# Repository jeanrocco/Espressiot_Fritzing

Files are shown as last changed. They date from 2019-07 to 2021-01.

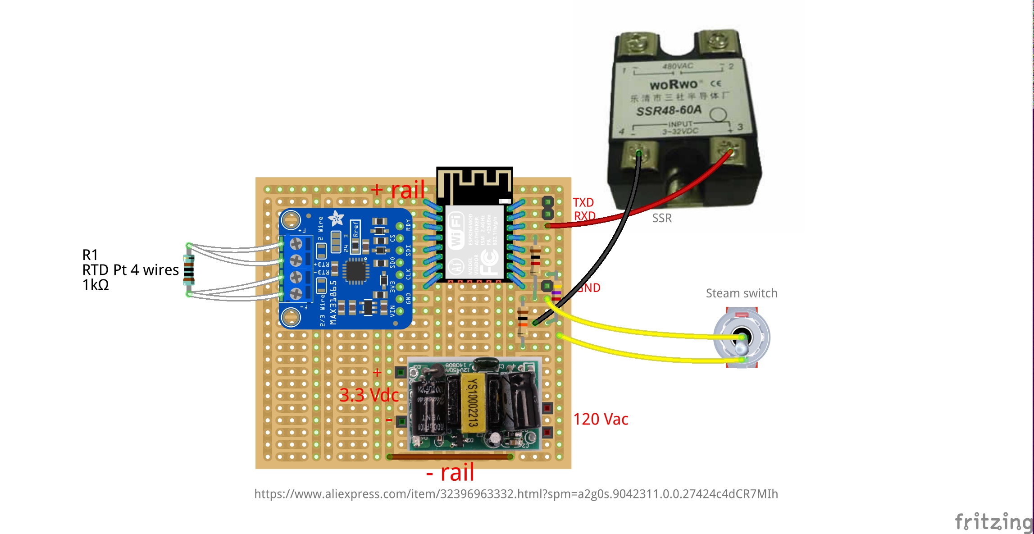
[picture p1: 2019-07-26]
Espressiot_final_bb.jpg

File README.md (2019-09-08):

# Espressiot_Fritzing

My implementation of Espressiot ( https://github.com/Schm1tz1/ESPressIoT ) ...

A good place to file my doc.

Added code for espressiot using a modified Adafruit MAX31865 RTD library and code for a second portable ESP8266 with Oled display.

I made the library non-blocking by changing the 10 msec. (bias enable) and a 65 msec. (conversion time) delays using millis().

I was having issues running the Oled display on the same Espressiot's ESP8266, too much delays I suppose. Lazily, after briefly looking for a non-blocking Oled driver, I decided to use a spare ESP8266 module whose sole purpose would be to get the temperature from an MQTT broker and display it on the Oled. This worked very well, and proved to be very flexible because it is portable.

Every second, the Espressiot-PID code "publishes" the RTD temperature to an MQTT broker, Mosquitto, which is running on a Raspberry PI (it was already running for Home Assistant...). Every 1/2 seconds, the Oled-display-ESP8266's code, which "subscribes" to the MQTT broker temperature, will update the Oled displays.

The file espressiotJR3b7c (https://github.com/jeanrocco/Espressiot_Fritzing/tree/master/espressiotJR3b7c) corrects the closed issue ESPressiot "Tuning loop not doing correct peak to peak temperature"  ( https://github.com/Schm1tz1/ESPressIoT/issues/2 ). This will allow a more accurate autotuning of the P, I and D parameters.

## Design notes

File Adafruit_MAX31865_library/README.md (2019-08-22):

# MODIFIED Adafruit_MAX31865
Arduino Library for Adafruit MAX31865 RTD Sensor

To make the library non-blocking, the "Adafruit_MAX31865::readRTD (void)" function will not be called because of the 10 and 65 msec. delays. It will be done externally using millis() function. In order to do that, "uint8_t  readRegister8(uint8_t addr);", "uint16_t readRegister16(uint8_t addr);" and "writeRegister8(uint8_t addr, uint8_t reg);" are made "public" in Adafruit_MAX31865.h .

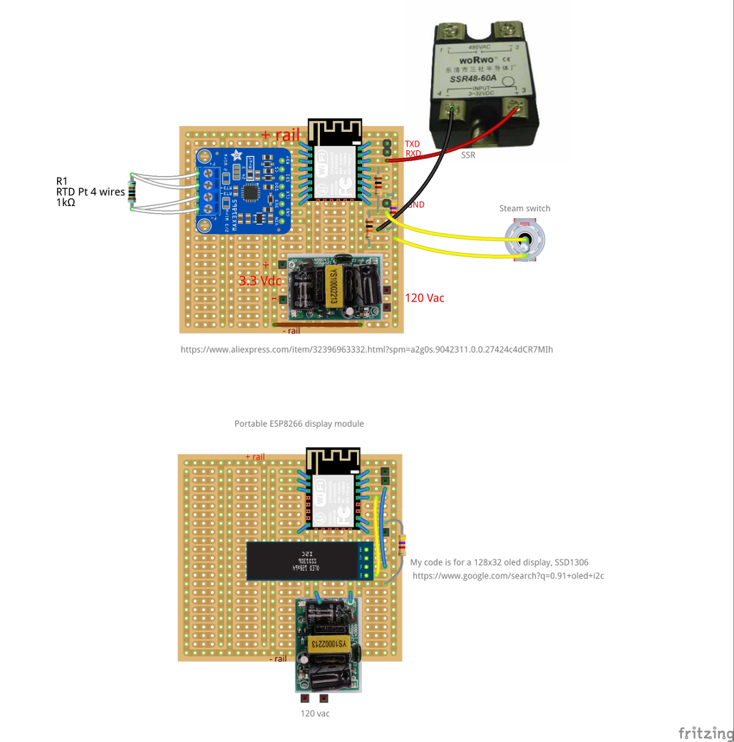
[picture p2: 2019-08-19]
Espressiot_final_Oled_bb_scaledd.png

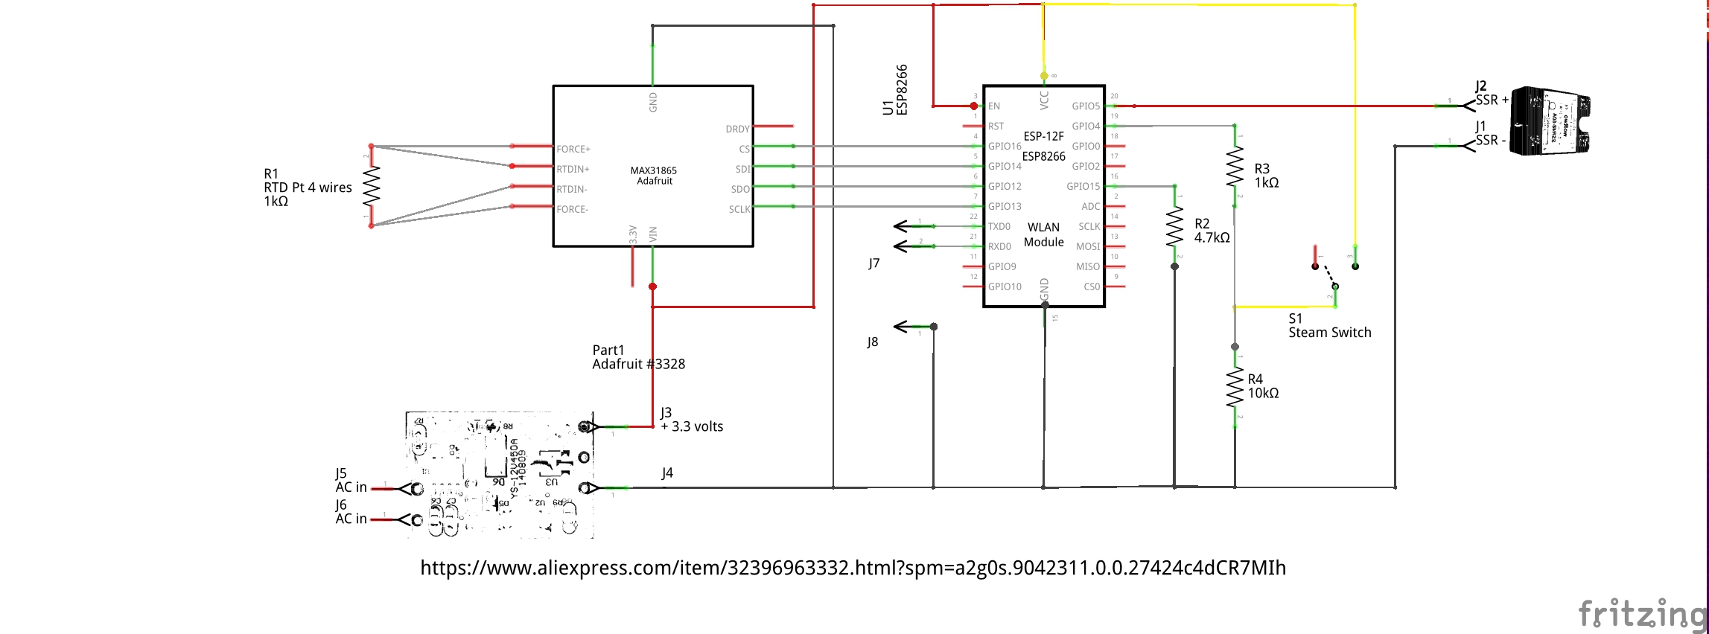
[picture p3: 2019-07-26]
Espressiot_final_schem.jpg

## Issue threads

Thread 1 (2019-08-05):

Autonomous portable temperature display - Code available?

VastSky, 2019-08-05:
Hello jeanrocco,

Your display solution sounds great!

Are you running a MQTT broker to that the autonomous portable temperature display subscribes to, or does the ESP8266 subscribe directly to the MQTT stream?

FYI - I found a great free MQTT tool:   http://mqtt-explorer.com/

Wondering if you might publish your ESP8266 code used for the display so I might attempt to make it work for myself.

Thanks,

Ed

jeanrocco, 2019-08-05:
Hello Ed,

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
I already had (have) an MQTT broker; “ Mosquitto”, running for "Home Assistant" on a dedicated Raspberry Pi. The ESP8266 running Espressiot publishes to topic "ESPressIoT/temp” and the other ESP8266 subscribes to it.
>
> FYI - I found a great free MQTT tool: http://mqtt-explorer.com/ <http://mqtt-explorer.com/>
>
I’m running MQTT.fx.app on a Mac now and then, your’s looks interesting though. I normally use the command line mosquitto_pub and  mosquitto_sub .
> Wondering if you might publish your ESP8266 code used for the display so I might attempt to make it work for myself.
>
>
I will do that as soon as I get back home, after Aug. the 14th, unfortunately I cannot "wake on lan" the machine where the code is right now. I will post how I modified Espressiot to slow down the publish to 1 sec. too. I’m using the standard https://github.com/olikraus/u8g2 <https://github.com/olikraus/u8g2> library.
So  till then !

Cheer !
jrb.
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

jeanrocco, 2019-08-07:
Hello ED,

Ok I uploaded my code to github, it is very crude but it works. I will try to clean it when I get home.

jrb.

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

jeanrocco, 2019-09-08:
Hello Ed.,  are you receiving this message ???

 I just saw that our friend Schm1tz1 locked the "Non blocking oled driver" repository where we were chatting...

About your MQTT broker question, as I explain in my Espressiot_Fritzing's README, I'm using an already existing broker/server running on a Raspberry pi. This was the easiest way for me since I'm running a Docker Home_Assistant app. (https://www.home-assistant.io/docs/installation/docker/) on that Raspberry pi, which contains the Mosquitto MQTT broker.

I just quickly glanced at some Google'd results and found out at "https://github.com/martin-ger/uMQTTBroker/tree/master/examples/uMQTTBrokerSampleOOFull" an interesting MQTT Arduino ESP8266 server that might work for you. I suppose you could just set up this server on the Oled Display ESP8266, since it is not very busy... and use it's built in MQTT client to subscribe to the local host 127.0.0.1 temperature topic. The other ESP8266 running Espressiot_PID would simply have to connect to this broker(server) as it currently does now for 192.168.1.120, in my case.

If you fell like doing this, let me know, I might be interested by this since it would be simpler to run the 2 ESP8266 without implying a third MQTT broker.

.... now that I think about it, when I'll be finished with my Rancillio project, I might look  more closely at that... that is an interesting solution... we'll keep in touch then.

jrb

VastSky, 2019-09-08:
Hey jeanrocco,

ed.rilkoff@ (google's popular email platform)  I thought we might leave Github for conversation.

I recently began to look ESP to ESP communication without the need for a router. ESP-now may do this.

https://forum.arduino.cc/index.php?topic=551310.0

https://www.reddit.com/r/arduino/comments/azlh6u/just_played_around_with_espnow_a_little_its/

I am going to look at using a ESP8266 as a MQTT broker. but, for now I must take care of home maintenance before poor weather arrives.

I have also been spending too much time trying to get a 6 hour 3D print in PETG to succeed. It is torturing me!

Ed

VastSky, 2021-01-24:
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

Hello jeanrocco,

I finally set up mosquito on my RPi, and built your autonomous portable temperature display. Everything works FANTASTIC!!
The response of the web interface is also much faster when accessing the IP of the EspressIoT - did you fix this?

I also updated to us your tuning with the "MaxUpperT=0, MaxLowerT=0" changes.

Would you have PID settings for the Miss Silvia that you like? I would love to try them.

Would you have any recommendations to use the PID tuning?

Thanks! - Ed

jeanrocco, 2021-01-25:
Hello Ed,

I haven't played with that code for awhile, I got bored by instabilities,
and finally bought a Dual boiler Breville all pid controlled... had a good
price (1000 can$) last year I couldn't resist ... not as solid as the
Rancillio, but makes an excellent coffee.

So the whole arduino pid just now sits in the forgotten pile... on my desk.
I spend my time on " Leaf firewall " development
which gives you a good firewall.

Ok my best wishes for 2021,

jrb.

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

VastSky, 2021-01-25:
Hey jeanrocco,

I agree that PID on a the miss Silvia single boiler will never be successful, but it is still an improvement over the mechanical thermostat. I enjoyed going through your contributions to the EspressIoT.

Glad you are enjoying the Breville. It is nice to have something that just works!

All the best,

Ed

jeanrocco, 2021-01-28:
Hello Ed,

Just not to let you believe I abandoned the ESP’s and Raspberry PIs, I still play with them, but a bit less. For the ESPs (esp8266 and esp32) I was happy to have found epressiot's application since right now, I have not found further interesting projects for them. My fondness for the PIs is still there, but I discarded it as a reliable platform, I now use a APU2E4 ( any APU2.. ) PC engine for my home assistant platform. This Soc is rock solid and never crashes. I run Ubuntu server on it and the Docker version of Home Assistant. I was doing the same last year with a PI but it crashed while I was vacationing down south (Florida :-)… and that’s a No No !!! Those APU2 are a very good inexpensive alternative compared to the Intel NUCs (pricy pricy ) and other Chinese equivalents that don’t necessarily have the encryption AES-NI hardware.

I gave you a hint of my current interest in the LEAF firewall, which runs here on a APU2C2 as my home firewall. If you look at https://bering-uclibc.zetam.org/wiki/Main_Page <https://bering-uclibc.zetam.org/wiki/Main_Page> at the version 5, 6 and 7 of the documentation you will have a glimpse at what I’m talking about. I’m currently, slowly, working on https://bering-uclibc.zetam.org/wiki/Bering-uClibc_7.x_-_User_Guide <https://bering-uclibc.zetam.org/wiki/Bering-uClibc_7.x_-_User_Guide> documentation, and if you read the chapters involving the PIs, you will see that installing a LEAF OS on one makes it a very reliable platform since everything from then on runs in RAM, no failure prone writes to the SD card anymore … You see there are still hopes for the PIs used that way :-). As a matter of fact I couldn’t resist buying myself a "PI Zero W", at 12.95$ Can. even if I have no use for it :-) …  I still can’t believe this 10$ (UStiny board holds a full fledge computer…

Ok so have fun with your projects, and I wish you the very best !

jrb.

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

VastSky, 2021-01-30:
Hey jeanrocco,

Thank you for sharing details on your projects!

It is very frustrating to have your remote monitoring fail when abroad.

The APU2E4 is intriguing hardware, especially with your application of hosting both home automation and LEAF firewall. That looks like a big learning curve. I intend to look at it in greater detail. What sort of home automation tasks have you deployed?

Reliable remote information is a must to give one peace of mind that everything is normal and secure at one's residence when you are away. I am a hobbyist that is easily distracted off course when something interesting presents, rather than maintaining focus on a project underway. I thus play with tech that is low budget like the ESP8266/32, RPi, sOnOff and ASUS wifi routers.

I buy off eBay, AliExpress and Banggood, mostly D1 mini, ESP-01S, NodeMCUv3, ESP32 DevC v4. DS18b20, BME280, BMP280, I2C OLEDs, and sOnOff.
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
VastSky, 2021-02-07:
Hello jeanrocco,

Thank you for the detailed information! I'm working through it. You really have taken HA and network security to the next level!

Do you slope or tow launch/thermal your sailplane? Are you familiar with **[dynamic soaring](https://www.youtube.com/watch?v=4eFD_Wj6dhk&feature=emb_logo)**?  The site I fly is slope, often with thermals. Built a few hotwire cut flying wings.

I discovered a very detailed, well documented **["Espresso-PID"](http://rancilio-pid.de/)** The setup was easy as I only needed to revise the IO, and OLED constructor to match my hardware, and it has DS18b20 as a sensor option.  The project has an active discord channel as well. I have been enjoying this project.

Ed

jeanrocco, 2021-02-08:
Hello Ed,

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
Just being careful :-) … and at the same time these projects keeps me abreast and aware of new technologies …
> Do you slope or tow launch/thermal your sailplane? Are you familiar with dynamic soaring <https://www.youtube.com/watch?v=4eFD_Wj6dhk&feature=emb_logo>? The site I fly is slope, often with thermals. Built a few hotwire cut flying wings.
>
>
I used a bungee for my first sailplane, a gentle lady , then switched to the much more convenient outer-runner motors and lipo batteries. Dynamic soaring requires mountains and a high degree of piloting skill, both of witch I lack :-) !!!

I climb up with the folding props electric motor to about 700 feet, and then hunt for thermals. On active days I can stay up until my transmitter battery weakens, couple of hours with my old NICad one. I used to fly at a club site for  RC control airplanes, and was making everyone jealous for staying in the air that long …

I’m using arf models, like Multiplex Easy glider pro. etc ... . We had a dude in our club that used a hotwire cutter, with steppers to drive it, but I didn’t used that, not enough patience. I don’t fly as much now, my evolving cataracts are slowing me down, and I’m waiting for the operation to clarify all that, well this year hopefully.
> I discovered a very detailed, well documented "Espresso-PID" <http://rancilio-pid.de/> The setup was easy as I only needed to revise the IO, and OLED constructor to match my hardware, and it has DS18b20 as a sensor option. The project has an active discord channel as well. I have been enjoying this project.
>
>
Ok I zipped through that but my german is not very good, and finally found the english docs. The only thing I didn’t like is this blynk cloud gizmo where you have to register for an account … it feels awkward or silly to need a web connection for making a cup of coffee :-) ! There are probably ways to go around that. So since you tried this PID, what are your comments, is it any good, stable and converging to a steady state set-point ???

Ok bye for now, fun exchanging with you as usual… btw where do you live ?

jrb.

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

VastSky, 2021-02-08:
Hello jeanrocco,

I live in Kamloops BC. You can take a look at my **[YT videos](https://www.youtube.com/user/cloudsuck/videos)** . Some of the scratch built stuff. I like planes that are fun and won't make me cry if I crash. Did a few tri and quadcopters too.

Google translate helped make reading through the German pretty simple. I am not using Blynk with it. It is MQTT capable, and wifi telnet serial debug capable which works nicely. Very well documented project. The single boiler of the Rancilio will never maintain a constant delivery temp of brew water, but this PID keeps the "set" temperature very stable without negligible overshoot. The Config.H is where you configure it all with good English comments. This project uses OTA flashing from the Arduino IDE which works well for configuration changes. Those Germans are overachievers!

Sorry to hear that you need to wait for the cataract surgery. I have friends that only wear weak reading glasses after surgery, and colors become vivid after surgery. If you can afford to, pay do it, and get the best surgeon and the best lenses.

Gotta run - at work and we have workers arriving that I must deal with.

Ed

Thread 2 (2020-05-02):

Using PT100RTD sensors and Adafruit MAX31865

ZH-A, 2020-05-02:
Hello! Can I ask some questions, as the author of Espressiot does not answer, but I am eager to understand how all this working))

I also use a similar sensor, only PT100 and with a library pt100rtd.h. But the components are not original, and the 2-wire sensor has a problem with self-heating, the sensor lies a lot when measured about 8 degrees, but after calibration it’s become in norm. Have you encountered such a problem? I would like to try using your code, but I am not good at programming and do not understand how the calibration mechanism can be implemented in your code?

Second question. Did not figure out how to connect to the MQTT server anywhere in the code there is no login and password for, can you tell me how this mechanism should work, please?

And the third problem with the PID. When I change the settings in the web interface is that practically nothing happens; the temperature curve does not change in any way, although the new coefficients are saved and displayed on the screen. Or do they only need to be changed only in code?

VastSky, 2020-05-02:
Sorry, I'm not proficient with code.

I referred to Schm1tz1/ earlier project "cofcon" to adapt the EspressIoT code for use with a DS18B20 temperature sensor. You can find the cofcon project at: https://github.com/Schm1tz1/cofcon

The only reason to use MQTT is to log data from the EspressIoT.  You can set up a MQTT broker on your PC or a Raspberry Pi:
http://www.steves-internet-guide.com/install-mosquitto-broker/
https://www.youtube.com/watch?v=xzHbMlFOu1E

The EspressIoT project is not a broker, but is is a client and will broadcast to a MQTT server. It does work. A nice tool to monitor the MQTT information is found at: http://mqtt-explorer.com/

The EspressIoT web interface does function to change coefficients and settings for me. I have not modified anything other than the temperature sensor type in the original code.

You might find similar projects that go into more explicit detail helpful that do temperature control such as sous vide, or beer brewing.

Good luck - best wishes!

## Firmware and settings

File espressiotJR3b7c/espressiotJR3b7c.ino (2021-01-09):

//
// ESPressIoT Controller for Espresso Machines
// 2016 by Roman Schmitz
//
// Uses PID library
//

#include <PID_v1.h>
#include <ESP8266WiFi.h>

// WIFI

#define WIFI_SSID "WIFI_ID"
#define WIFI_PASS "WIFI_password"

// options for special modules
#define ENABLE_JSON
#define ENABLE_HTTP
#define ENABLE_MQTT

// use simulation or real heater and sensors
//#define SIMULATION_MODE

//
// STANDARD reset values based on Gaggia CC
//
#define S_P 150.0
#define S_I 0.75
#define S_D 500.
#define S_aP 500.0
#define S_aI 0.0
#define S_aD 0.0
#define S_TSET 90.0
#define S_TBAND 5.0

//
// Intervals for I/O
//
#define HEATER_INTERVAL 1000
#define DISPLAY_INTERVAL 1000
#define PID_INTERVAL 200

//
// global variables
//
double gTargetTemp=S_TSET;
double gOvershoot=S_TBAND;
double gInputTemp=20.0;
double gOutputPwr=0.0;
double gP = S_P, gI = S_I, gD = S_D;
double gaP = S_aP, gaI = S_aI, gaD = S_aD;

double tictic=gTargetTemp;

double MaxUpperT=0, MaxLowerT=0;                // declared here to allow cute "serial plotter" output...

unsigned long time_now=0;
unsigned long time_last=0;

boolean tuning = false;
boolean osmode = false;
boolean poweroffMode = false;

int tic = 0;

//
// gloabl classes
//
PID ESPPID(&gInputTemp, &gOutputPwr, &gTargetTemp, gP, gI, gD, P_ON_E, DIRECT);



void setup()
{
  gOutputPwr=0;
  pinMode(4 , INPUT);
  Serial.begin(115200);

  Serial.println("Mounting SPIFFS...");
  if(!prepareFS()) {
    Serial.println("Failed to mount SPIFFS !");
  } else {
    Serial.println("Mounted.");
  }

  /*if (!saveConfig()) {
    Serial.println("Failed to save config");
  } else {
    Serial.println("Config saved");
  }*/

  Serial.println("Loading config...");
  if (!loadConfig()) {
    Serial.println("Failed to load config. Using default values and creating config...");
    if (!saveConfig()) {
     Serial.println("Failed to save config");
    } else {
      Serial.println("Config saved");
    }
  } else {
    Serial.println("Config loaded");
  }
   
  Serial.println("Settin up PID...");

  WiFi.begin(WIFI_SSID, WIFI_PASS);
  Serial.println("");
  Serial.print("MAC address: ");
  Serial.println(WiFi.macAddress());

  while (WiFi.status() != WL_CONNECTED) {
    delay(500);
    Serial.print(".");
  }
  
  Serial.println("");
  Serial.println("WiFi connected.");
  Serial.print("IP address: ");
  Serial.println(WiFi.localIP());

  #ifdef ENABLE_HTTP
  setupWebSrv();
  #endif
  
  #ifdef ENABLE_MQTT
  setupMQTT();
  #endif

  // setup components
  setupHeater();
  setupSensor();

  // start PID
  ESPPID.SetTunings(gP, gI, gD, P_ON_E);
  ESPPID.SetSampleTime(PID_INTERVAL);
  ESPPID.SetOutputLimits(0, 1000);
  ESPPID.SetMode(AUTOMATIC);
 
  time_now=millis();
  time_last=time_now;
    
}

void serialStatus() {
  Serial.print(gInputTemp, 2); Serial.print(" ");
  Serial.print(gTargetTemp, 2); Serial.print(" ");
  Serial.print(tictic, 2); Serial.print(" ");
  Serial.print(MaxLowerT, 2); Serial.print(" ");      // have a look at the " Tools -> Serial Plotter " when running auto-tune
  Serial.print(MaxUpperT, 2); Serial.print(" ");      // this gives a cute display !
//  Serial.print(time_now); Serial.print(" ");
//  Serial.print(gOutputPwr, 2); Serial.print(" ");
//  Serial.print(gP, 2); Serial.print(" ");
//  Serial.print(gI, 2); Serial.print(" ");
//  Serial.print(gD, 2); Serial.print(" ");
//  Serial.print(ESPPID.GetKp(), 2); Serial.print(" ");
//  Serial.print(ESPPID.GetKi(), 2); Serial.print(" ");
//  Serial.print(ESPPID.GetKd(), 2); Serial.print(" ");
//  Serial.print(digitalRead(4));
  Serial.println("");
}

void loop() {
  time_now=millis();

  updateTempSensor(); 
  gInputTemp=getTemp();

  if(abs(time_now-time_last)>=PID_INTERVAL or time_last > time_now) {
    if(poweroffMode==true) {
      gOutputPwr=0;
      setHeatPowerPercentage(0);
    }
    else if(tuning==true)
    {
      tuning_loop();
    }
    else  {
      if( !osmode && abs(gTargetTemp-gInputTemp)>=gOvershoot ) {        
        ESPPID.SetTunings(gaP, gaI, gaD, P_ON_E);
        osmode=true;
      }
      else if( osmode && abs(gTargetTemp-gInputTemp)<gOvershoot ) {
        ESPPID.SetTunings(gP,gI,gD,P_ON_E);
        osmode=false;
      }
      if(ESPPID.Compute()==true) {   
        setHeatPowerPercentage(gOutputPwr);
      }
    }        
    
    #ifdef ENABLE_MQTT
    loopMQTT();
    #endif

    if (tic == 0) tictic = gTargetTemp +1;
    serialStatus();
    tic++;
    tictic = gTargetTemp;
    if (tic == 5) tic = 0;
    
    time_last=time_now;
  }

  updateHeater();
  
  #ifdef ENABLE_HTTP
  loopWebSrv();
  #endif 
  
}

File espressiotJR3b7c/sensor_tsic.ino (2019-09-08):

//
// ESPressIoT Controller for Espresso Machines
// 2016 by Roman Schmitz
//
// TSIC-Sensors using Arduino-TSIC-Library
//

#ifndef SIMULATION_MODE

//#include <TSIC.h>
#include <Adafruit_MAX31865.h>


//Use software SPI: CS, DI, DO, CLK
Adafruit_MAX31865 maxJR = Adafruit_MAX31865(16, 14, 12, 13);
 
//#define TSIC_SIG 4 // D4 pin of NodeMCU just in the right position


#define RREF       4300.0      // resistance de reference
#define RNOMINAL   1000.0      // rtd a 0 C.

int SMP_TIME1 = 10;   // pour le bias enable...
int SMP_TIME2 = 65;   // pour le one shot, qui demarre la conversion
uint16_t cnt1 = 0; uint16_t cnt2 = 0;
int nread = 8;        // nombre de valeurs analogiques pour la moyenne...
boolean biasEnab = false;
boolean oneShot = false;

float readings[8];
uint16_t idx = 0;
float total = 22.0 * nread;
float moy = 22.0;

 
//#define ACCURACY 0.1

//TSIC TSens1(TSIC_SIG);

float lastT = 0.0;
float SumT = 0.0;
float lastErr = 0.0;
int CntT = 0;
uint16_t raw_temp = 0;
unsigned long lastSensTime;
uint8_t sm = 1;                 // demarre avec l'etat 1...
uint16_t rtd = 1000;

void setupSensor() {  
  maxJR.begin(MAX31865_4WIRE);  // set to 2WIRE or 4WIRE as necessary
  for ( int lect = 0; lect < nread; lect++ ) {  // initialize 8 readings to 22.0 degres...
    readings[lect] = 22.0;
  }
  total = 22.0 * nread;
//  lastSensTime=millis();
  sm = 1;                       // etat 1...
}

void updateTempSensor() {
  
  switch (sm) {

    case 1:
      
      maxJR.clearFault();
      maxJR.enableBias(true);
      lastSensTime = millis();
      cnt1 = 0; cnt2 = 0;
      sm = 2;
      break;
      
    case 2:

      cnt1++;
      if (abs(millis() - lastSensTime) >= SMP_TIME1) {
        
        uint8_t registre = maxJR.readRegister8(0);  // lire le registre de configuration adr 0
        registre |= 0x20;                           // le bit pour oneshot
        maxJR.writeRegister8(0, registre);          // et demarre la conversion
        lastSensTime = millis();
        sm = 3;
        
      }
     break;
      
    case 3:

       cnt2++;
       if (abs(millis() - lastSensTime) >= SMP_TIME2) {

        rtd = maxJR.readRegister16(0x01);
        rtd >>= 1;                                  // enleve le bit fault...
        float curT = maxJR.temperature(RNOMINAL, RREF, rtd);
      
/*      // very simple selection of noise hits/invalid values 
        if(abs(curT-lastT)<1.0 || lastT<1) {
        SumT+=curT;
        CntT++;        
        } 
*/
        total = total - readings[idx];    // enleve la derniere valeur...
        readings[idx] = curT;
        total = total + readings[idx];
        idx++;
        if (idx >= nread) {
          idx = 0;
        }

        
        sm = 1; 
        
//        Serial.print("cnt1 = "); Serial.print(cnt1); Serial.print("  cnt2 = "); Serial.println(cnt2);
//        J'ai ~ 70 usec de loop ... cnt1= 144 pour 10 msec et cnt2= 929 pour 65 msec... ca clanche en ta !
       }

       
      break;
  }
  
  
  
/*  if (abs(millis() - lastSensTime) >= TSIC_SMP_TIME) {
    if(TSens1.getTemperature(&raw_temp)) {
      float curT = TSens1.calc_Celsius(&raw_temp);

      // very simple selection of noise hits/invalid values 
      if(abs(curT-lastT)<1.0 || lastT<1) {
        SumT+=curT;
        CntT++;        
      }     
      lastSensTime=millis();
    }
  } */ 
}

float getTemp() {
  float retVal=gInputTemp;

/*    if(CntT>=1) {
    retVal=(SumT/CntT);
    SumT=0.;
    CntT=0;
  }
//  retVal = maxJR.temperature(RNOMINAL, RREF, rtd);
*/
  retVal = total/nread;                   // divise par 8

  return retVal;
}

#endif

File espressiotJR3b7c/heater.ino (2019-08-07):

//
// ESPressIoT Controller for Espresso Machines
// 2016 by Roman Schmitz
//
// Simplified Heater PWM - just connect SSR to HEAT_RELAY_PIN
//

#define HEAT_RELAY_PIN 5 // D5 + GND are close on NodeMCU

float heatcycles; // the number of millis out of 1000 for the current heat amount (percent * 10)

boolean heaterState = 0;
unsigned long heatCurrentTime = 0, heatLastTime = 0; 

#ifndef SIMULATION_MODE
void setupHeater() {
  pinMode(HEAT_RELAY_PIN , OUTPUT);
}

void updateHeater() {
  boolean h;
  heatCurrentTime = time_now;
  if(heatCurrentTime - heatLastTime >= HEATER_INTERVAL or heatLastTime > heatCurrentTime) { //second statement prevents overflow errors
    // begin cycle
    _turnHeatElementOnOff(1);  // 
    heatLastTime = heatCurrentTime;   
  } 
  if (heatCurrentTime - heatLastTime >= heatcycles) {
    _turnHeatElementOnOff(0);
  }
}
#endif

void setHeatPowerPercentage(float power) {
  if (power < 0.0) {
    power = 0.0;
  }  
  if (power > 1000.0) {
    power = 1000.0;
  }
  heatcycles = power;
}

float getHeatCycles() {
  return heatcycles;
}

void _turnHeatElementOnOff(boolean on) {
  digitalWrite(HEAT_RELAY_PIN, on); //turn pin high
  heaterState = on;
}

// End Heater Control
